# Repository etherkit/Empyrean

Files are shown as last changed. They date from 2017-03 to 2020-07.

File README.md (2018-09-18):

# Empyrean

### Installing Empyrean Support in Arduino IDE

1. Open the Arduino IDE and then navigate to the Preferences screen by selecting the ```File``` menu, and then ```Preferences```. Click the small button to the right of the text box labeled ```Additional Boards Manager URLs```, and then paste the following URL into the windows which pops up:
[https://github.com/etherkit/ArduinoBoards/raw/master/package_etherkit_index.json](https://github.com/etherkit/ArduinoBoards/raw/master/package_etherkit_index.json)
<br>Click OK to close this window, and then OK to close the Preferences.
2. Navigate to the Arduino Boards Manager in the IDE by selecting the ```Tools``` menu, then ```Board```, and then ```Boards Manager...```. In the search box in the upper right of the Boards Manager windows, type ```SAMD```.
3. In the search results list below, find the entry for ```Arduino SAMD Boards```, select it with your mouse, and then click the install button.
4. Next, find the entry for ```Etherkit SAMD Boards```, select it, and click the install button. Close the Boards Manager window when this is complete.
5. In the ```Tools > Boards``` menu, you should now see Empyrean Alpha and Empyrean Beta listed as board options. Select the appropriate board in order to start uploading sketches to your Empyrean.

### USB-UART (CDC) and Other Serial
You can access the built-in USB-UART (virtual serial port) by using the ```SerialUSB``` object in your sketch, just as you use ```Serial``` in AVR-powered Arduinos. You can also use pins 0 and 1 of Empyrean as a hardware serial port with the ```Serial1``` object.

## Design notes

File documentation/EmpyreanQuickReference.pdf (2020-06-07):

3.3V

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
AREF

VUSB

GND

3.3V

VIN

SDA

SCL

MOSI
MISO
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
SCLSCL
SDA

MOSI

MISO
SCK

Serial1

I²C

SPI

SerialUSB

A0
A1
A2
A3
A4
A5

A0

3.3V Regulated
Ground

Ground

3.3V Regulated

USB Bus Voltage (~5V)
Ext. Voltage In (5-16V)*

*VUSB and VIN are electrically connected; they can be isolated by cutting JP1. WARNING: Do not connect a voltage source to VIN if Empyrean is already connected to USB! If you do, the host and/or Empyrean will likely be damaged!

Reset (Pull to Ground)

# Empyrean Alpha/Beta

# Quick Reference

## Revision 1 — 6 Jun 2020 For Empyrean Alpha/Beta Rev A

Ref.

PWM No PWM

### Pin Label Digital Pin Serial ADC DAC Power

Board Specifications | Pin Legend
IC

### Clock Speed Flash Storage RAM

### Dimensions

### ADC DAC Input Voltage

### Pin Current Board Current

### Pin Voltage

Microchip Technology ATSAMD21G18A (Alpha) Microchip Technology ATSAMD21G16B (Beta) 48 MHz
256 kB (Alpha)/64 kB (Beta)
*8 kB flash storage reserved for bootloader 32 kB (Alpha)/8 kB (Beta)
12-bit, 6 available input pins
10-bit, 1 available output pin
5 VDC regulated (from USB or on VUSB pin) 3.3 VDC regulated (on 3.3V pin)
5-16 VDC (on VIN pin)
3.3 VDC maximum
7 mA sink/source
150 mA total board current
45 mm (L) x 18 mm (W) x 1.2 mm (H)

## Power Options

The most common option for powering Empyrean is via the USB port. The on-board voltage regulator provides 3.3 V to the microcontroller from the 5 V USB bus. You may provide your own 5 V regulated supply to the VUSB pin if the board is not connected to USB. Empyrean can also accept a 5-16 V power supply on the VIN pin (see important note below). Finally, you may supply 3.3 V regulated to the 3.3V pin if the board is to be used stand-alone after programming.

JP1 Connects 5V USB bus to Empyrean VIN bus (which provides 5V to the 3.3V voltage regulator). Cut jumper to use an external voltage source without risk
of damaging USB host.
JP2 Cut jumper to disable the red power LED. Located on back of PCB.

## Jumpers

Empyrean comes with a bootloader preinstalled for easy Arduino sketch loading. You may load a sketch onto Empyrean by either using the Arduino IDE upload function or by mounting Empyrean on your PC as a storage device with a quick double-press of the RESET button and dragging a sketch in UF2 format to the window.

## Bootloader

RESET Button Single press: Reset and execute sketch
Double press: Enter bootloader mode

### Function Digital Pin

## On-Board LEDs

### Active

D3 | User LED | HIGH
D1 | UART TX | LOW
D2 | UART RX | LOW

13

### D4 Power

26

25

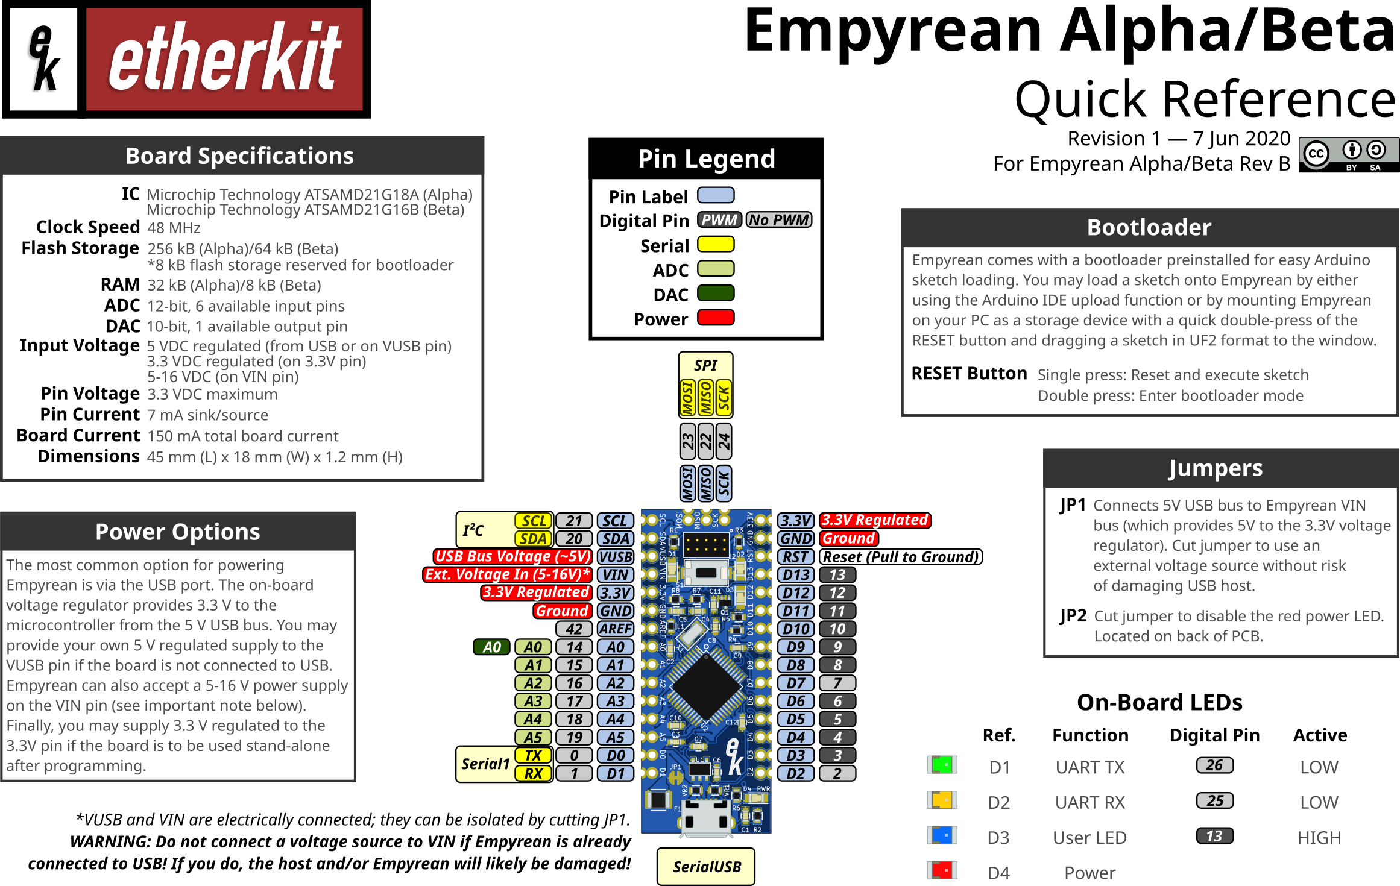
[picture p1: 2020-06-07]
documentation/EmpyreanQuickReference.png

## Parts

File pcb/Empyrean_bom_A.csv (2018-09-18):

Component | Description | Part | References | Value | Footprint | Quantity Per PCB | Datasheet
1 |  | C | C6 C8 C10 C11 C12 | 100n | C_0603 | 5
2 |  | C | C2 C7 | 10u | C_0603 | 2
3 |  | C | C4 C5 | 15 | C_0603 | 2
4 |  | C | C3 C9 | 1u | C_0603 | 2
5 |  | C | C1 | 4.7n | C_0603 | 1
6 |  | LED | D3 | Blue | Lite-On_LTST-C170 | 1
7 |  | LED | D4 | Green | Lite-On_LTST-C170 | 1
8 |  | LED | D1 | Red | Lite-On_LTST-C170 | 1
9 |  | LED | D2 | Yellow | Lite-On_LTST-C170 | 1
10 |  | FUSE | F1 | Bel 0ZCH0050FF2G | R_1210 | 1
11 |  | CONN_01X15 | J4 J5 | CONN_01X15 | Pin_Header_Straight_1x15_NoBorder | 2
12 |  | USB_OTG | J1 | FCI 10118194-0001LF | FCI_10118194-0001LF | 1
13 |  | CONN_02X05 | J2 | Harwin M50-3500542 | Harwin_M50-3500542 | 1
14 |  | CONN_01X03 | J3 | SPI | Pin_Header_Straight_1x03_NoBorder | 1
15 |  | JUMPER | JP1 | Power LED Enable | SOLDER_JUMPER | 1
16 |  | L | L1 | 10u | R_0603 | 1
17 |  | MOS_N | Q1 Q4 | DMG1012UW-7 | SOT523 | 2
18 |  | MOS_P | Q2 Q3 | DMG1013T-7 | SOT523 | 2
19 |  | R | R5 R7 R8 | 100k | R_0603 | 3
20 |  | R | R10 | 10k | R_0603 | 1
21 |  | R | R2 | 1M | R_0603 | 1
22 |  | R | R1 R3 R4 R6 R9 R11 | 330 | R_0603 | 6
23 |  | PUSHBUTTON | S1 | Alps SKQMASE010 | Alps_SKQMASE010 | 1
24 |  | ATSAMD21G18A | U2 | ATSAMD21GxA | TQFP-48_7x7mm_Pitch0.5mm | 1 | DOCUMENTATION
25 |  | LP2985 | U1 | LP2985 | SOT23-5 | 1
26 |  | VR | VR1 VR2 | CG0603MLC-05E | R_0603 | 2
27 |  | CRYSTAL | X1 | ECS-.327-12.5-34B-TR | ECS_ECS-.327-12.5-34B-TR | 1
Component Groups: | 27
Component Count: | 45
Fitted Components: | 45
Number of PCBs: | 1
Total components: | 45
Schematic Version: | A
Schematic Date: | 2017-03-04
BoM Date: | Tue 18 Sep 2018 02:25:04 PM PDT
Schematic Source: | /home/jason/Nextcloud/Etherkit/git/Empyrean/pcb/Empyrean.sch
KiCad Version: | Eeschema 5.0.0-fee4fd1~66~ubuntu18.04.1

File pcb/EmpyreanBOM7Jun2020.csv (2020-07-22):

Part/Designator | Manufacture Part Number/Seeed SKU | Quantity
F1 | 0ZCH0050FF2G | 1
J1 | 10118194-0001LF | 1
Q1 | 2N7002TQ-7-F | 1
U2 | ATSAMD21G18A-AUT | 1
C3,C9 | CC0603KRX5R8BB105 | 2
C6,C8,C10,C11,C12 | CC0603KRX7R9BB104 | 5
C1 | CC0603KRX7R9BB472 | 1
C2,C7 | CC0603MRX5R5BB106 | 2
VR1,VR2 | CG0603MLC-05E | 2
X1 | ECS-.327-12.534B-TR | 1
C4,C5 | GCM1885C1H150JA16D | 2
U1 | LP2985-33DBVR | 1
D1 | LTST-C170KGKT | 1
D4 | LTST-C170KRKT | 1
D2 | LTST-C170KSKT | 1
D3 | LTST-C170TBKT | 1
L1 | MLF1608E100JT000 | 1
R2 | RC0603FR-071ML | 1
R1,R3,R4,R5,R6,R8 | RC0603FR-07330RL | 6
R7 | RC0603JR-0710KL | 1
S1 | SKQMASE010 | 1

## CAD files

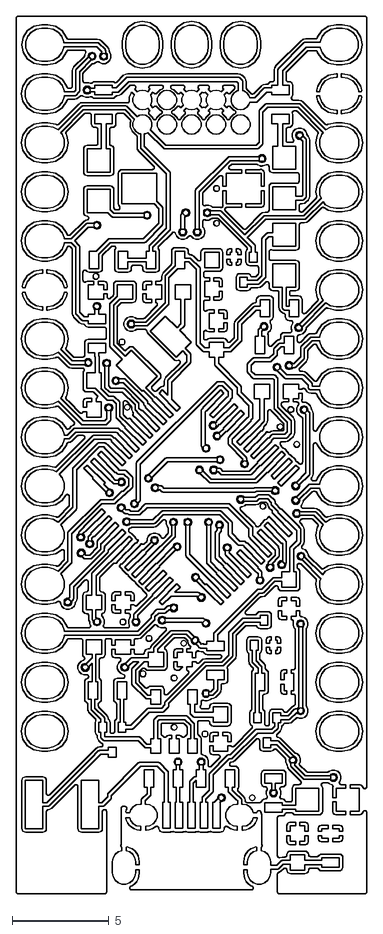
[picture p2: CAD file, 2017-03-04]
pcb/Empyrean-F.Cu.dxf
18.1 x 45.5

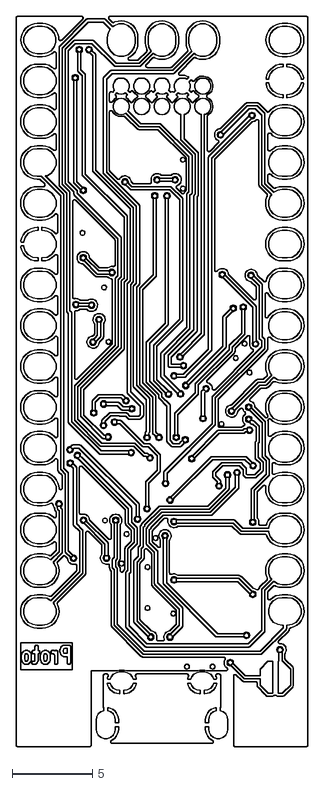
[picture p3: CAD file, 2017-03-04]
pcb/Empyrean-B.Cu.dxf
18.1 x 45.5

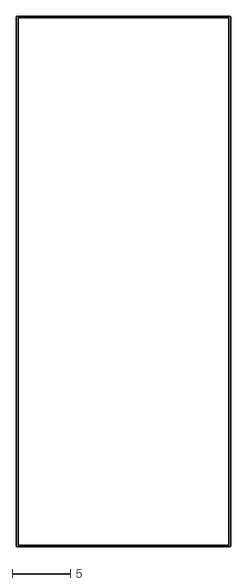
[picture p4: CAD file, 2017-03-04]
pcb/Empyrean-Edge.Cuts.dxf
18.5 x 45.8

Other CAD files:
pcb/EmpyreanDrill.dxf
pcb/Empyrean-B.Mask.dxf
pcb/Empyrean-B.Paste.dxf
pcb/Empyrean-B.SilkS.dxf
pcb/Empyrean-F.Mask.dxf
pcb/Empyrean-F.Paste.dxf
pcb/Empyrean-F.SilkS.dxf

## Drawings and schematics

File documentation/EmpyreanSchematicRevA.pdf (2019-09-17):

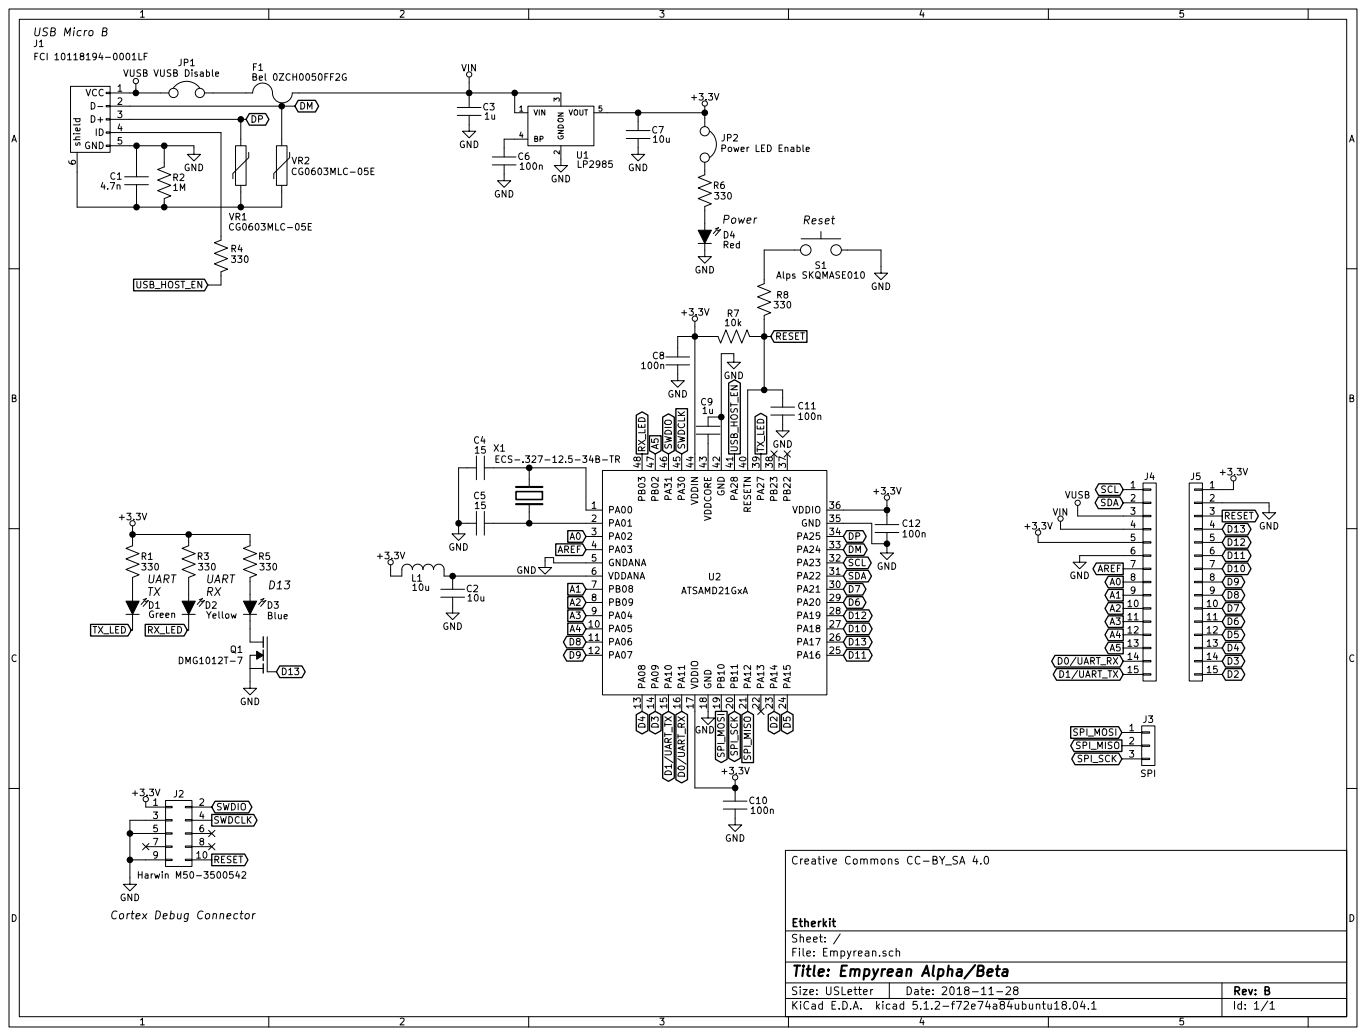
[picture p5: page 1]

+3.3V GND GND GND GND

Id: 1/1 Title: Empyrean Alpha/Beta

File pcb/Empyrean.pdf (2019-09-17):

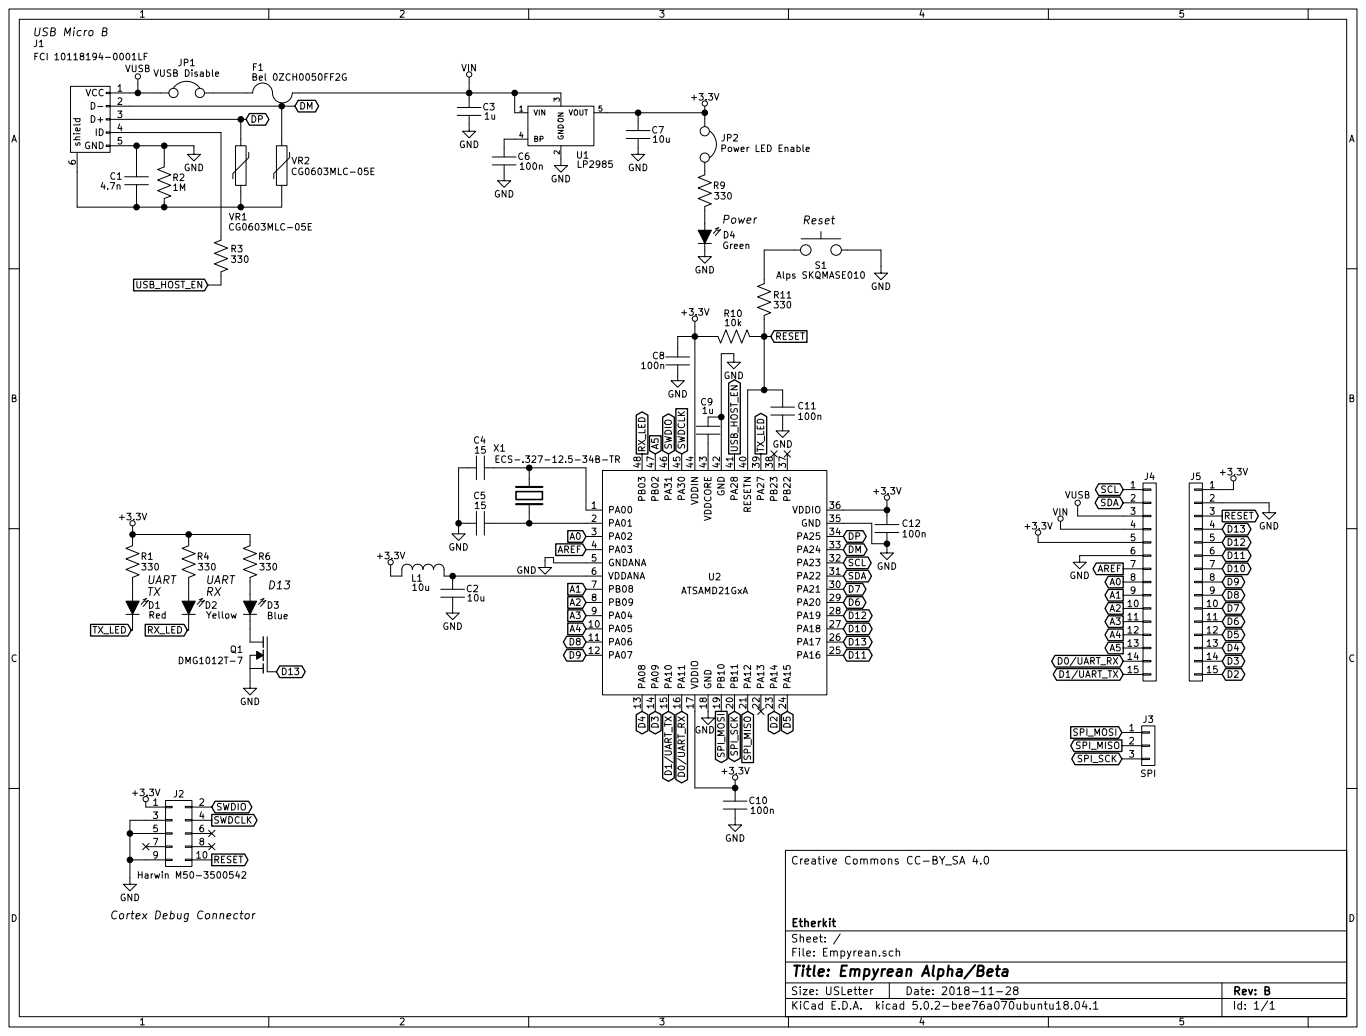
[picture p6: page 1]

+3.3V GND GND GND GND

Id: 1/1 Title: Empyrean Alpha/Beta

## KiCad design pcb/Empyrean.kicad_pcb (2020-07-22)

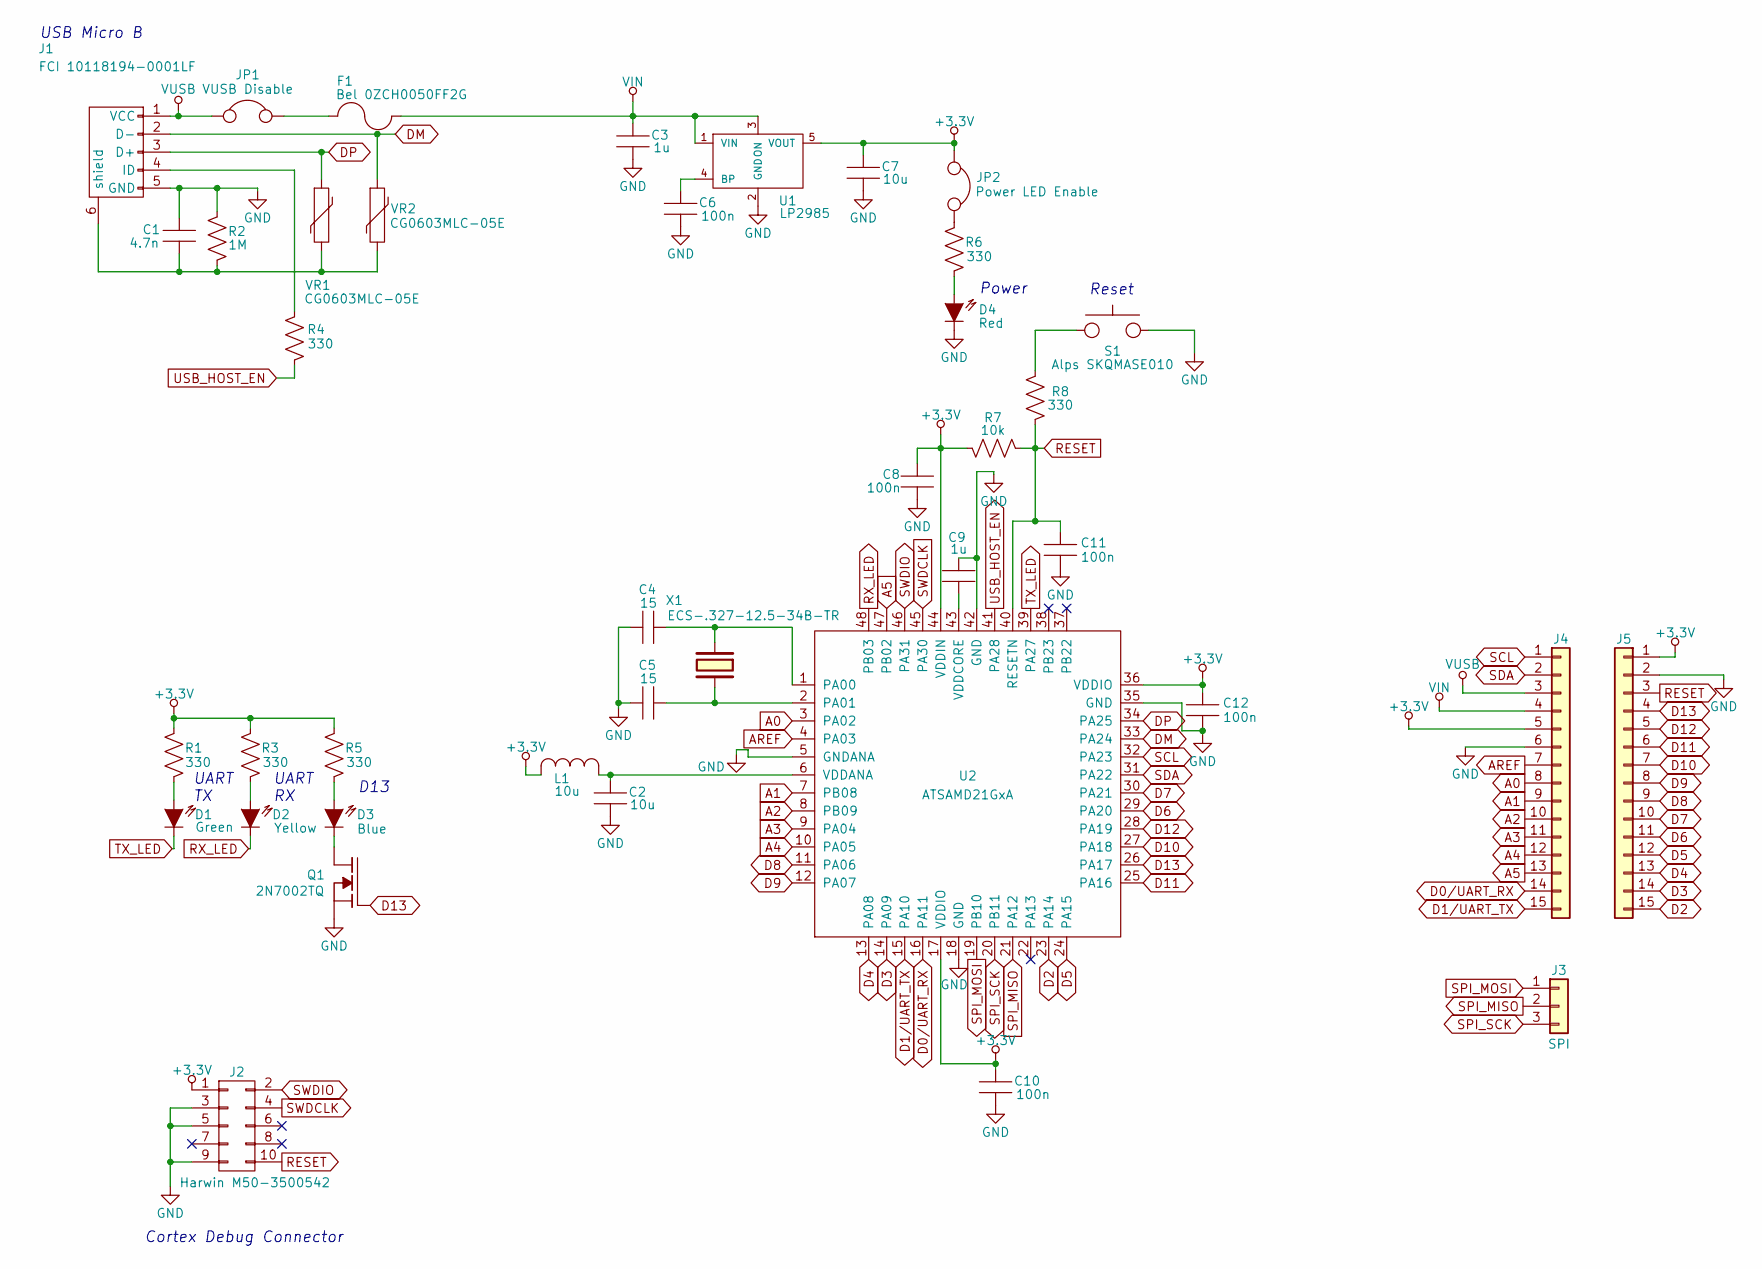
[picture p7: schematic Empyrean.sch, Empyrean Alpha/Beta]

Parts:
C1: 4.7n; C_0603; MPN CC0603KRX7R9BB472
C2, C7: 10u; C_0603; MPN CC0603MRX5R5BB106
C3, C9: 1u; C_0603; MPN CC0603KRX5R8BB105
C4, C5: 15; C_0603; MPN GCM1885C1H150JA16D
C6, C8, C10, C11, C12: 100n; C_0603; MPN CC0603KRX7R9BB104
D1: Green; Lite-On_LTST-C170; MPN LTST-C170KGKT
D2: Yellow; Lite-On_LTST-C170; MPN LTST-C170KSKT
D3: Blue; Lite-On_LTST-C170; MPN LTST-C170TBKT
D4: Red; Lite-On_LTST-C170; MPN LTST-C170KRKT
F1: Bel 0ZCH0050FF2G; R_1210; MPN 0ZCH0050FF2G
J1: FCI 10118194-0001LF; FCI_10118194-0001LF; MPN 10118194-0001LF
J2: Harwin M50-3500542; Harwin_M50-3500542
J3: SPI; Pin_Header_Straight_1x03_NoBorder
J4, J5: CONN_01X15; Pin_Header_Straight_1x15_NoBorder
JP1: VUSB Disable; SOLDER_JUMPER_NC
JP2: Power LED Enable; SOLDER_JUMPER_NC
L1: 10u; R_0603; MPN MLF1608E100JT000
Q1: 2N7002TQ; SOT523; MPN 2N7002TQ-7-F
R1, R3, R4, R5, R6, R8: 330; R_0603; MPN RC0603FR-07330RL
R2: 1M; R_0603; MPN RC0603FR-071ML
R7: 10k; R_0603; MPN RC0603JR-0710KL
S1: Alps SKQMASE010; Alps_SKQMASE010; MPN SKQMASE010
U1: LP2985; SOT23-5; MPN LP2985-33DBVR
U2: ATSAMD21GxA; TQFP-48_7x7mm_Pitch0.5mm; MPN ATSAMD21G18A-AUT
VR1, VR2: CG0603MLC-05E; R_0603; MPN CG0603MLC-05E
X1: ECS-.327-12.5-34B-TR; ECS_ECS-.327-12.5-34B-TR; MPN ECS-.327-12.534B-TR

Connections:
+3.3V: C7.1, C8.1, C10.1, C12.1, J2.1, J4.5, J5.1, JP2.1, L1.1, R1.1, R3.1, R5.1, R7.1, U1.5 (VOUT), U2.17 (VDDIO), U2.36 (VDDIO), U2.44 (VDDIN)
A0: J4.8, U2.3 (PA02)
A1: J4.9, U2.7 (PB08)
A2: J4.10, U2.8 (PB09)
A3: J4.11, U2.9 (PA04)
A4: J4.12, U2.10 (PA05)
A5: J4.13, U2.47 (PB02)
AREF: J4.7, U2.4 (PA03)
D0/UART_RX: J4.14, U2.16 (PA11)
D1/UART_TX: J4.15, U2.15 (PA10)
D2: J5.15, U2.23 (PA14)
D3: J5.14, U2.14 (PA09)
D4: J5.13, U2.13 (PA08)
D5: J5.12, U2.24 (PA15)
D6: J5.11, U2.29 (PA20)
D7: J5.10, U2.30 (PA21)
D8: J5.9, U2.11 (PA06)
D9: J5.8, U2.12 (PA07)
D10: J5.7, U2.27 (PA18)
D11: J5.6, U2.25 (PA16)
D12: J5.5, U2.28 (PA19)
D13: J5.4, Q1.2 (G), U2.26 (PA17)
DM: J1.2 (D-), U2.33 (PA24), VR2.1
DP: J1.3 (D+), U2.34 (PA25), VR1.1
GND: C1.1, C2.2, C3.2, C4.2, C5.2, C6.2, C7.2, C8.2, C9.1, C10.2, C11.2, C12.2, D4.2 (K), J1.5 (GND), J2.3, J2.5, J2.9, J4.6, J5.2, Q1.1 (S), R2.1, S1.2, U1.2 (GND), U2.5 (GNDANA), U2.18 (GND), U2.35 (GND), U2.42 (GND)
unnamed: C1.2, J1.6 (shield), R2.2, VR1.2, VR2.2
unnamed: C2.1, L1.2, U2.6 (VDDANA)
unnamed: C4.1, U2.1 (PA00), X1.1
unnamed: C5.1, U2.2 (PA01), X1.2
unnamed: C6.1, U1.4 (BP)
unnamed: C9.2, U2.43 (VDDCORE)
unnamed: D1.1 (A), R1.2
unnamed: D2.1 (A), R3.2
unnamed: D3.1 (A), R5.2
unnamed: D3.2 (K), Q1.3 (D)
unnamed: D4.1 (A), R6.2
unnamed: F1.1, JP1.2
unnamed: J1.4 (ID), R4.2
unnamed: JP2.2, R6.1
unnamed: R8.1, S1.1
RESET: C11.1, J2.10, J5.3, R7.2, R8.2, U2.40 (RESETN)
RX_LED: D2.2 (K), U2.48 (PB03)
SCL: J4.1, U2.32 (PA23)
SDA: J4.2, U2.31 (PA22)
SPI_MISO: J3.2, U2.21 (PA12)
SPI_MOSI: J3.1, U2.19 (PB10)
SPI_SCK: J3.3, U2.20 (PB11)
SWDCLK: J2.4, U2.45 (PA30)
SWDIO: J2.2, U2.46 (PA31)
TX_LED: D1.2 (K), U2.39 (PA27)
USB_HOST_EN: R4.1, U2.41 (PA28)
VIN: C3.1, F1.2, J4.4, U1.1 (VIN), U1.3 (ON)
VUSB: J1.1 (VCC), J4.3, JP1.1

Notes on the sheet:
Reset
Cortex Debug Connector
USB Micro B
Power
UART TX
UART RX
D13

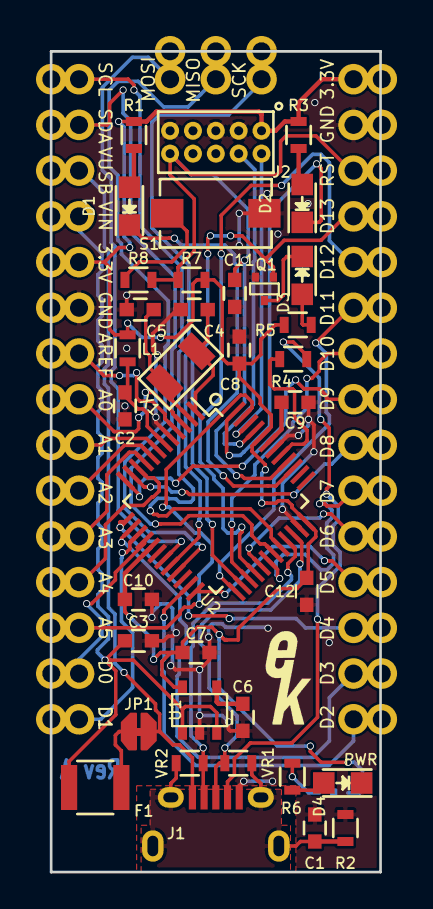
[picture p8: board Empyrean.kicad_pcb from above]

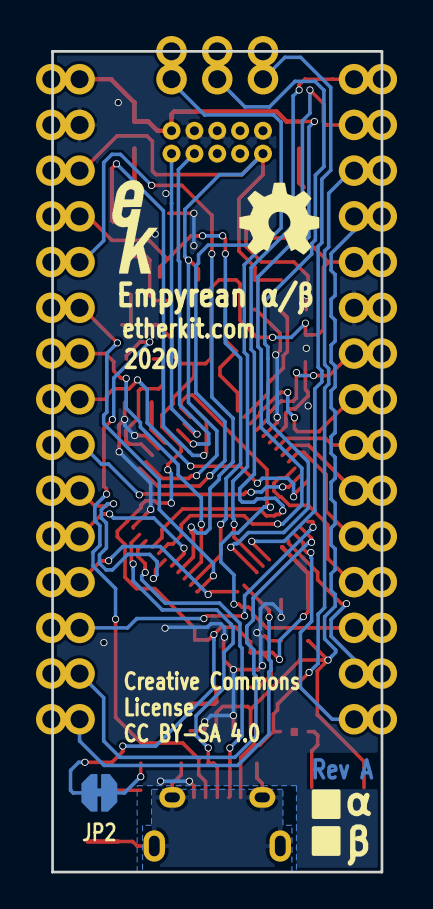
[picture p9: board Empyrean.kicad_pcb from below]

Board: 2 copper layers, 18.3 x 45.6 mm, 42 parts (2 on the bottom side), 53 nets.

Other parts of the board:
Ref**: Val**; EtherkitLogoSmall
Ref**#2: Val**; EtherkitLogoSmall

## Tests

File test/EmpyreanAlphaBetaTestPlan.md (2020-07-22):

# Empyrean Alpha/Beta Test Plan

Revision: 7 Jun 2020

**This document is preliminary and a work in progress. It will be subject to modification as necessary for support Empyrean production.**

## Product Profile

Empyrean is a powerful yet affordable Arduino IDE-compatible microcontroller derived from the Arduino Zero. It is in a small, breadboard friendly form factor and costs significantly less than the Arduino Zero due to the omission of the rarely-used debugging IC and associated hardware.

## Test Procedure Overview

The purpose of the test is to ensure electrical connectivity for every GPIO pin on Empyrean. It will be assumed that if basic electical connectivity can be confirmed via GPIO that the pin peripherals on the microcontroller will also function correctly. A visual check that all on-board LEDs are functional is also required. The ATSAMD21 microcontroller will not need to be programed via the debug header, as these devices will be ordered from Microchip Technology with the bootloader pre-installed.

0. SETUP: connect test jig to PC, open serial terminal to jig.
1. Place DUT in jig, connect DUT to PC via micro USB.
2. Load test sketch to DUT and reset DUT.
3. Reset jig to execute GPIO test.
4. After GPIO test completes, verify all 4 LEDs function by eye.
5. On test completion, disconnect DUT, goto step 1 if further DUT to test.

## Tools

|Device|Quantity|Comment|
|---|---|---|
| PC | 1 | Any OS which can run Arduino IDE |
| Empyrean test jig | 1 | |
| Micro USB cable | 2 | For connecting test jig and DUT to PC |

## Required Program Files

TBD

## Detailed Test Procedure

TBD

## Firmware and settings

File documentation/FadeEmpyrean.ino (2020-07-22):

/*
 Fade

 This example shows how to fade an LED on pin 13
 using the analogWrite() function.

 The analogWrite() function uses PWM, so if
 you want to change the pin you're using, be
 sure to use another PWM capable pin. On most
 Arduino, the PWM pins are identified with 
 a "~" sign, like ~3, ~5, ~6, ~9, ~10 and ~11.

 This example code is in the public domain.
 */

int brightness = 0;    // how bright the LED is
int fadeAmount = 5;    // how many points to fade the LED by

// the setup routine runs once when you press reset:
void setup()
{
  // declare pin to be an output:
  pinMode(LED_BUILTIN, OUTPUT);
}

void loop() {
 
  // set the brightness of pin:
  analogWrite(LED_BUILTIN, brightness);

  // change the brightness for next time through the loop:
  brightness = brightness + fadeAmount;

  // reverse the direction of the fading at the ends of the fade:
  if (brightness <= 0 || brightness >= 255)
  {
    fadeAmount = -fadeAmount;
  }
  
  // wait for 30 milliseconds to see the dimming effect
  delay(30);
}

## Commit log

2017-03-05 Generate gerbers
    [Empyrean-B.Cu.gbr, Empyrean-B.Mask.gbr, Empyrean-B.SilkS.gbr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]
2018-03-01 Add basic board support instructions to README
2018-09-18 Add csv BOM
    [Empyrean-2018-09-18-14-24-46.sch, Empyrean_bom_A.csv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]
2018-11-28 Update schematic to Rev B
    [Empyrean.sch]
2019-09-17 Updated PCB with castellation
    [Empyrean-B.Cu.gbl, Empyrean-B.Mask.gbs, Empyrean-B.SilkS.gbo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]
2020-06-07 Add Empyrean Quick Reference
    [Empyrean.kicad_pcb]
2020-07-22 Set proper rev on documentation
    [Empyrean-NPTH.drl, Empyrean-PTH.drl, Empyrean.gbl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]

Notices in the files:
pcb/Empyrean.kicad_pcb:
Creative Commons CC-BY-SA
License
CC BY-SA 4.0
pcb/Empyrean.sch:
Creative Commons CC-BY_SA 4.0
